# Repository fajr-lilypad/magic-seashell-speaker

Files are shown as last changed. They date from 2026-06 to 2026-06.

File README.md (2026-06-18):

# Seashell Speaker!

A bluetooth speaker that automatically plays when tilted, encased in a seashell case!

  

I came up with this idea when I was thinking about how to expand my audio projects. This was created for hackclub's fallout program, and after first creating an mp3 player, I though the next step would be to make something that could use bluetooth, and then I took it to the next level by making it tilt activated! By coincidence, this is my second ocean-related project, lol. The design was inspired by the story we all know about hearing the ocean come from a shell, and partly inspired by the purple magic conch shell from spongebob, lol.



# Cad Screenshots

<table>
   <tr>
      <td>
   
</td>
      <td>
   
      </td>
   </tr>
</table>

<table>
  <tr>
    <td>
    
    </td>
    <td>
    
    </td>
    <td>
      
    </td>
  </tr>
</table>

Cad Notes:
- Okay, so CAD took a WHILE. Creating such an organic shape was difficult, so ended up relying on the revolve, sweep, and coil tools. Since there arent any tutorials online for creating this type of shell in Fusion either, I had to experiment with blender along with borrowing pieces of 3d models online. Once I had a shape i was happy with, I turned it into a case by splitting it in half, adding holes for magnets, and enclosure for the speaker standoffs for the pcb, and holes for the speaker wires.
- The case itself is pretty easy to use, and I'm happy with how it turned out. If I could go back and change anything, I'd definetly check before hand that my case and pcb were compatible. Orginally, I had planned to tuck my pcb away in the lip/opening of the shell. However, that would be pretty mush impossible without making a HUGE shell case, so I had to basically do a whole redesign of the pcb and case.

# PCB Screenshots

<table>
  <tr>
    <td>
    
    </td>
    <td>
    
    </td>
    <td>
      
    </td>
  </tr>
</table>

  PCB Notes:
   - For the PCB, I did have to go thorugh a few versions. I mostly focused on creating super compact board without hindering the esp32's antenna, which wasn't too bad. However, my first designs were too big too fit in the case, so I had to go back to the drawing board, where I decided to make a round pcb that would sit between the top and bottom halves of the shell.
   - This pcb includes a tilt sensor, charging module, switch, esp32, speaker output headers, and more (see bom)

# Schematic Screenshot
 
 

 # Zine !!



 # BOM

 | Item                 | Purpose                       | #        | Cost   | Supplier           | Link                                                                                                                                                                                                                                                                                                                                                                                                                                                                                                                                                                                                                                                                                                                                                                                                                                                                                                                                       |
|----------------------|-------------------------------|----------|--------|--------------------|--------------------------------------------------------------------------------------------------------------------------------------------------------------------------------------------------------------------------------------------------------------------------------------------------------------------------------------------------------------------------------------------------------------------------------------------------------------------------------------------------------------------------------------------------------------------------------------------------------------------------------------------------------------------------------------------------------------------------------------------------------------------------------------------------------------------------------------------------------------------------------------------------------------------------------------------|
| SW-520D              | Sensor                        | 1        | $1.13  | Aliexpress         | https://www.aliexpress.us/item/3256805875302445.html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                                                                                                                                                                |
| ESP32                | Microcontroller               | 1        | $3.13  | Aliexpress         | https://www.aliexpress.us/item/3256807714347051.html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           |
| MAX98357A            | Amplifier                     | 1        | $1.78  | Aliexpress         | https://www.aliexpress.us/item/3256805196806369.html?gatewayAdapt=glo2usa4itemAdapt                                                                                                                                                                                                                                                                                                                                                                                                                                                                                                                                                                                                                                                                                                                                                                                                                                                        |
| Small Round Magnets  | Enclosure snaps               | 1        | $0.99  | Aliexpress         | https://www.aliexpress.us/item/3256810289404806.html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                                                                                                                                                   |
| 15mm speaker         | Speaker                       | 1        | $2.17  | Aliexpress         | https://www.aliexpress.us/item/3256809180147331.html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 |
| 3.7V Lithium Battery | Battery                       | 1        | $6.67  | Aliexpress         | https://www.aliexpress.us/item/3256803431098963.html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                                                                                                                                                                                                                                                                             |
| TP4056 Module        | Charging Module               | 1        | $0.82  | Aliexpress         | https://www.aliexpress.us/item/3256808777213556.html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                                                                                                                                                                                         |
| AP2112K              | Voltage Regulator             | 1        | $0.26  | Mouser             | https://www.mouser.com/ProductDetail/Diodes-Incorporated/AP2112K-33TRG1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                                                                                                                                                                                                                                                                                                                                                                                                                                                                                                                                                                                                                                                                                                                                                        |
| 3Pin Slide Switch    | Off/On                        | 1        | $0.90  | Aliexpress         | https://www.aliexpress.us/item/2255801021214741.html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                                                                                                                                                   |
| CH340C               | Serial Chip                   | 1        | $0.94  | Aliexpress         | https://www.aliexpress.us/item/3256809981619787.html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                                                                                                                                                   |
| JST 2 Pin Connector  | battery input, speaker output | 2        | $1.97  | Aliexpress         | https://www.aliexpress.us/item/3256808498055527.html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                                                                                                                                                    |
| USB C Receptacle     | Data Input                    | 1        | $2.02  | Aliexpress         | https://www.aliexpress.us/item/3256809263109556.html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                                                                                                                                                               |
| WS2812B              | LED                           | 2        | $0.20  | Ebee               | https://www.ebee.com/product-detail/worldsemi-ws2812b-v5-w_617514.html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                                                                                                                                                                                                                                                                                                                                                                                                                                                                                                                                                                                                                                                                                |
| 74ACHCT125           | Quad Level Shifter            | 1        | $1.50  | Adafruit           | https://www.adafruit.com/product/1787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                                                                                                                                                                                                                                                                                                                                                                                                                                                                                                                                                                                                                                                                                                                  |
| 10uF C               | Capacitor                     | 3        | $0.40  | Digikey            | https://www.digikey.com/en/products/detail/kyocera-avx/REA0511100M025K/20096372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                                                                                                                                                                                                                                                                                                                                                                                                                                                                                                                                                                                                                                                          |
| 0.1uF C              | Capacitor                     | 5        | $0.32  | Sparkfun           | https://www.sparkfun.com/capacitor-ceramic-0-1uf.html                                                                                                                                                                                                                                                                                                                                                                                                                                                                                                                                                                                                                                                                                                                                                                                                                                                                                      |
| 5.1K R               | Resistor                      | 2        | $0.08  | Electronix Express | https://www.elexp.com/products/130155-1kres-1-watt-5-5-1-k-ohm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                                                                                                                                                                                                                                                                                                                                                                                                                                                                                                                                                                                                                                                               |
| 330 R                | Resistor                      | 1        | $0.15  | Newark             | https://www.newark.com/multicomp-pro/mccfr01sj0331a10/carbon-film-resistor-330-ohm-1w/dp/59K8549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|pcrid||plid||kword||match|e|slid||product|59K8549|pgrid|1231453304461926|ptaid|pla-4580565455222458|&msclkid=0d6d44d2aa3b1af1a3812efec2f401f3                                                                                                                                                                                                                                                                                                                                                                                                                                                                                                                                                                                                                                                     |
| 10K R                | Resistor                      | 3        | $0.19  | Newark             | https://www.newark.com/multicomp-pro/mf12-10k/res-10k-125mw-axial-metal-film/dp/38K5401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                                                                                                                                                                                                                                                                                                                                                                                                                                                                                                                                                                                                                   |
| 100K R               | Resistor                      | 1        | $0.24  | Newark             | https://www.newark.com/ohmite/mox70031003bye/resistor-metal-film-100k-0-25w/dp/49AJ2825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|pcrid||plid||kword||match|e|slid||product|49AJ2825|pgrid|1231453304461926|ptaid|pla-4580565455222458|&msclkid=8346f4e1e0f2133c086d9ecd89969e59                                                                                                                                                                                                                                                                                                                                                                                                                                                                                                                                                                                                                                                             |
| S8050                | Transistor                    | 1        | $0.84  | Aliexpress         | https://www.aliexpress.us/item/3256808228534673.html?src=google&gatewayAdapt=glo2usa                                                                                                                                                                                                                                                                                                                                                                                                                                                                                                                                                                                                                                                                                                                                                                                                                                                       |
| BC847                | Transistor                    | 1        | $0.19  | Mouser             | https://www.mouser.com/ProductDetail/Nexperia/BC847235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                                                                                                                                                                                                                                                                                                                                                                                                                                                                                                                                                                        |
| PCB Order            | PCB                           | 1        | $2.10  | JLCPCB             |                                                                                                                                                                                                                                                                                                                                                                                                                                                                                                                                                                                                                                                                                                                                                                                                                                                                                                                                            |
|                      |                               | Subtotal | $28.99 |                    |                                                                                                                                                                                                                                                                                                                                                                                                                                                                                                                                                                                                                                                                                                                                                                                                                                                                                                                                            |

## Firmware

Unlike my previous audio projects, instead of using a micro sd card storing songs played by a df player, I used bluetooth connection via an esp32 and a BluetoothA2DPSink library I found from user pschatzmann. The code is fairly simple, and checks the tilt sensor in the background periodically, intercepting when a tilt is detected to pause/play audio.

## Build Guide
1. 3D print Case, ensure that standoffs and holes are secure and remove all supports.
2. Collect all electronic parts and perform breadboard testing before soldering onto custom pcb
3. Flash fimrware with new pcb, connect to bluetooth so you see "Bluetooth Speaker Audio Ready to Pair!" message printed.
4. Test out tilt puasing/playing audio
5. Mount fully charged pcb onto built in standoffs in top of case.
6. Place speaker in enclosure, thread wires through holes and plug into headers in pcb.
7. Place magnets in small holes in shell case, snap case shut.

## Notes and Acknowledgements
- Thank you to *hackclub* and the *fallout* team for this oppurtunity and for making this project possible!

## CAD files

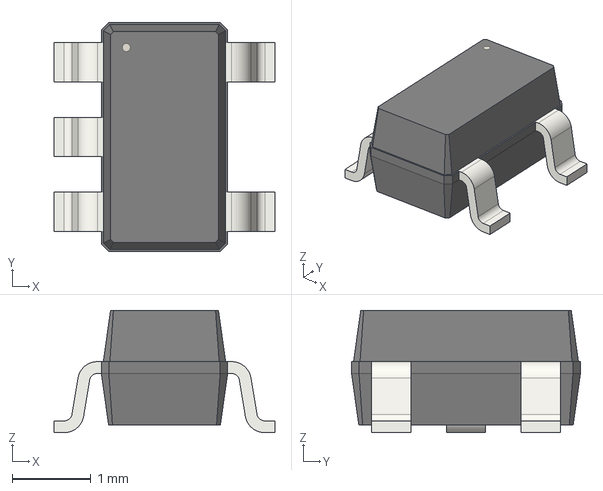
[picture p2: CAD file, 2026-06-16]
CAD/PCB Files/Electronics/SOT-23-5.step
2.80 x 2.90 x 1.55 mm

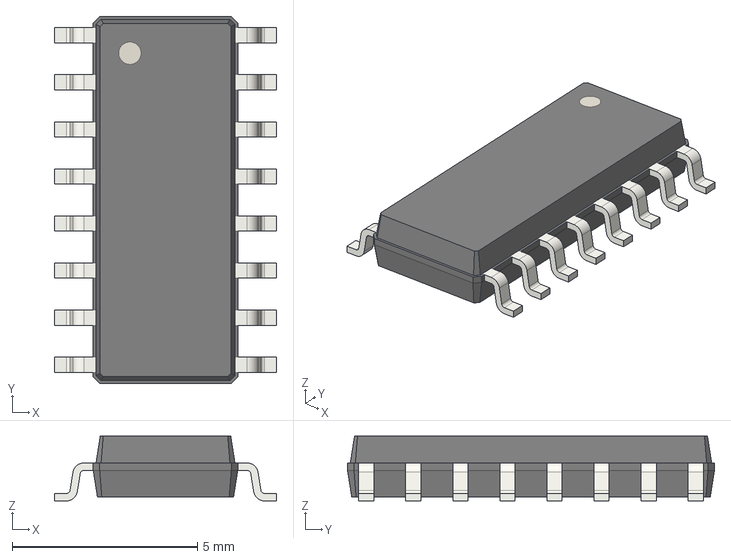
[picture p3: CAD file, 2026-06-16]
CAD/PCB Files/Electronics/SOIC-16_3.9x9.9mm_P1.27mm.step
6.00 x 9.90 x 1.75 mm

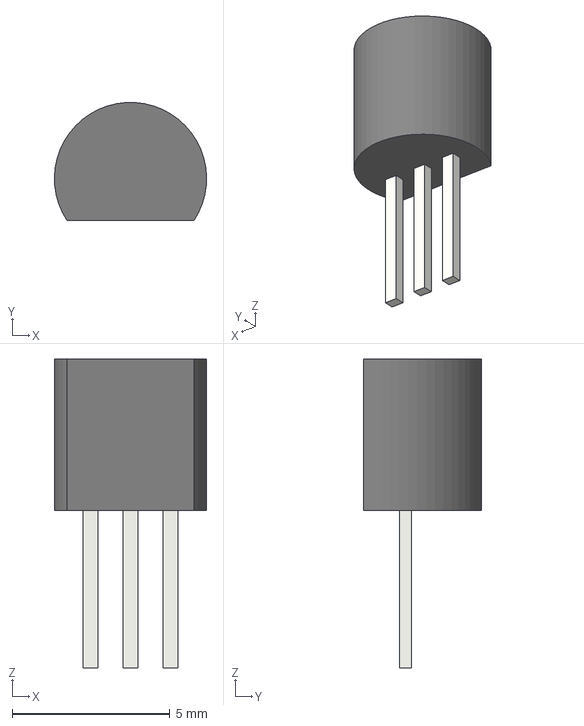
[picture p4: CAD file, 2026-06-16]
CAD/PCB Files/Electronics/TO-92_Inline Transistor.step
4.83 x 3.74 x 9.80 mm

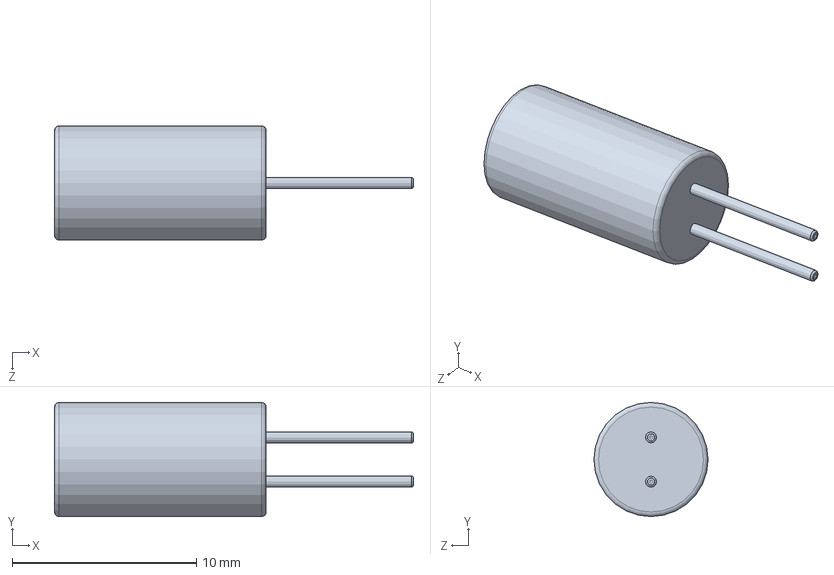
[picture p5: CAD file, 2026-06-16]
CAD/PCB Files/Electronics/SW-520D.SLDPRT
19.5 x 6.20 x 6.20 mm

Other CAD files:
pcb (no components).step

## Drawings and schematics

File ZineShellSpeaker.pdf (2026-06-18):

# magic shell bluetooth

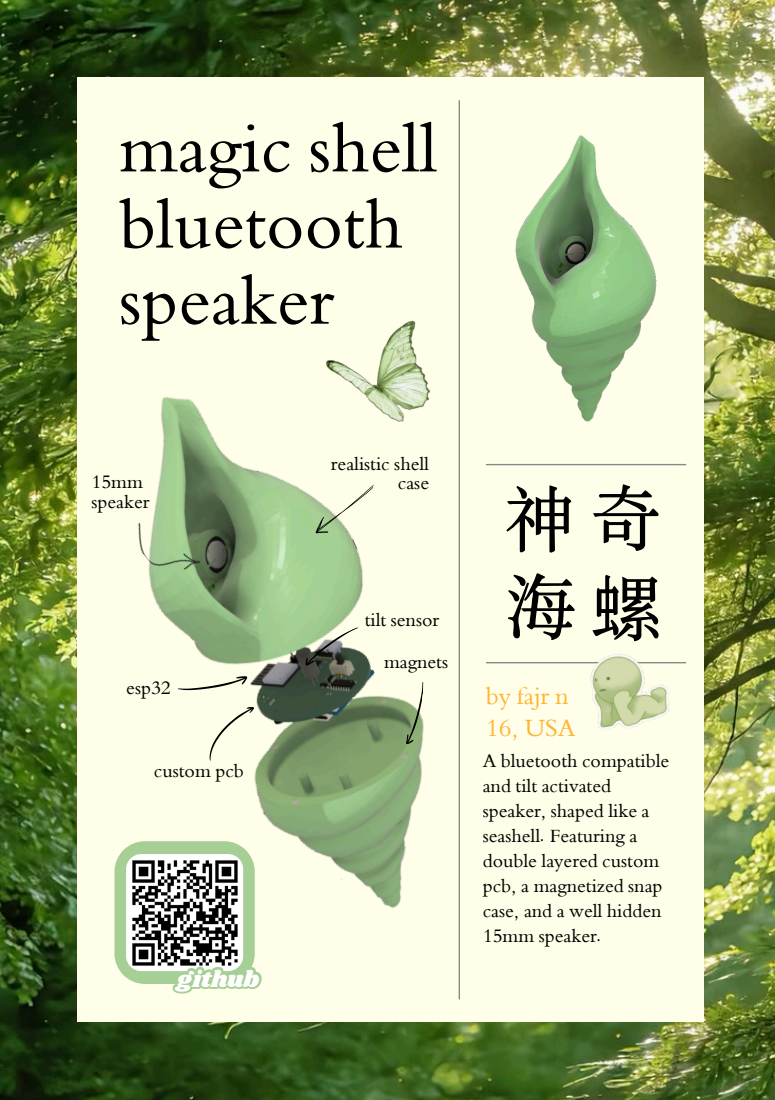
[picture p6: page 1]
speaker; custom pcb; realistic shell; case; esp32; ggiitthhuubb

tilt sensor
magnets
by fajr n
16, USA
A bluetooth compatible
and tilt activated
speaker, shaped like a
seashell. Featuring a
double layered custom
pcb, a magnetized snap
case, and a well hidden
15mm speaker.

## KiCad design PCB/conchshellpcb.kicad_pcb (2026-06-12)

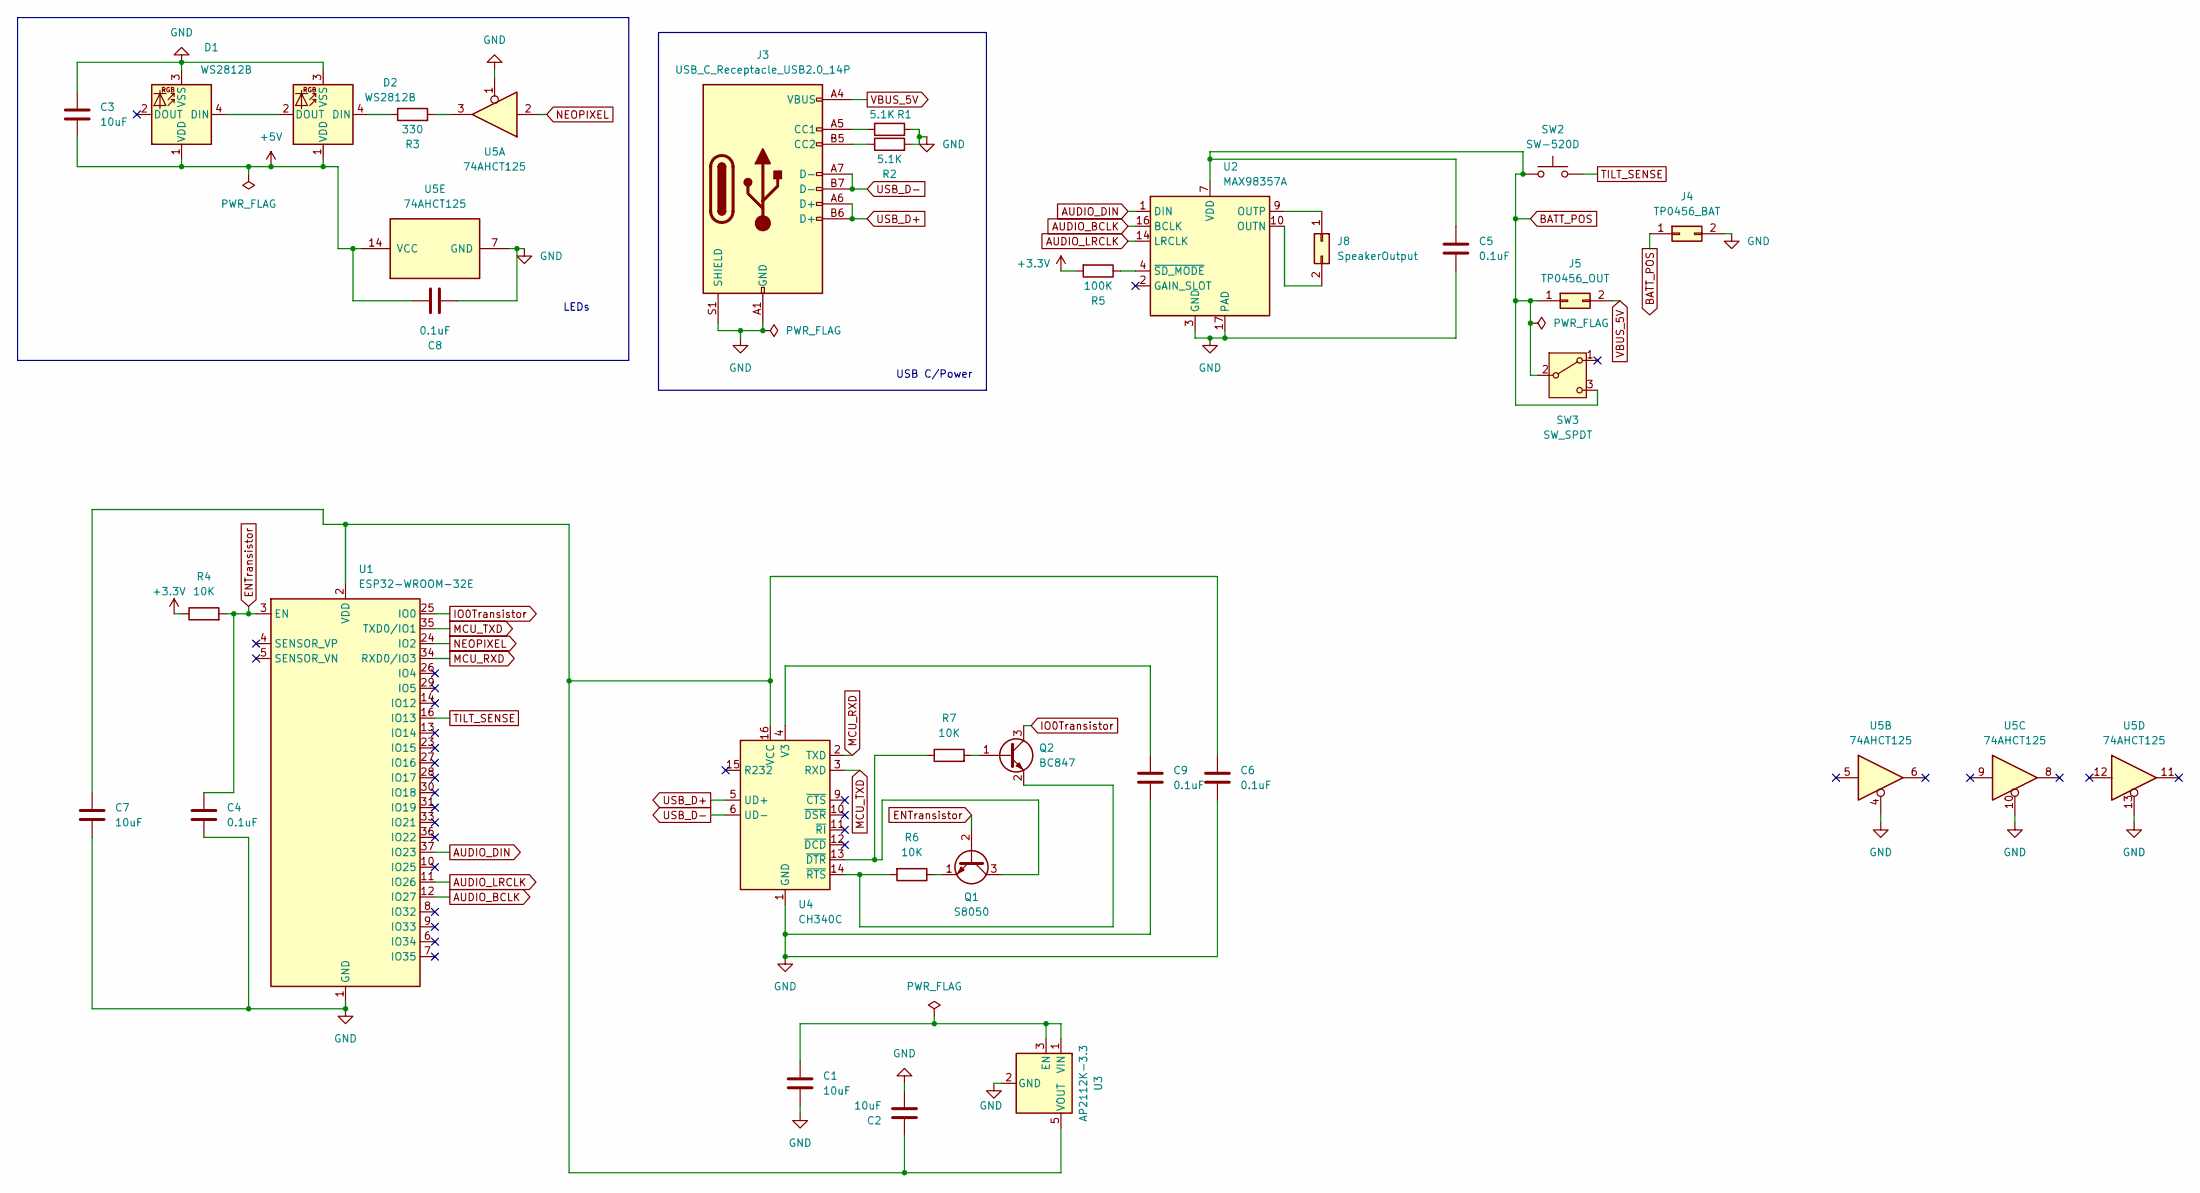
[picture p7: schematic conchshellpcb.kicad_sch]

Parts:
C1, C2, C3, C7: 10uF; C_0603_1608Metric
C4, C5, C6, C8, C9: 0.1uF; C_0402_1005Metric
D1, D2: WS2812B; LED_WS2812B_PLCC4_5.0x5.0mm_P3.2mm
J3: USB_C_Receptacle_USB2.0_14P; USB_C_Receptacle_HRO_TYPE-C-31-M-12
J4: TP0456_BAT; Batside
J5: TP0456_OUT; Outside
J8: SpeakerOutput; PinHeader_1x03_P2.54mm_Vertical
Q1: S8050; TO-92_Inline
Q2: BC847; SOT-23
R1, R2: 5.1K; R_0402_1005Metric
R3: 330; R_0402_1005Metric
R4, R6, R7: 10K; R_0402_1005Metric
R5: 100K; R_0402_1005Metric
SW2: SW-520D; PinHeader_1x02_P2.54mm_Vertical
SW3: SW_SPDT; SW_Slide_SPDT_Straight_CK_OS102011MS2Q
U1: ESP32-WROOM-32E; ESP32-WROOM-32D
U2: MAX98357A; TQFN-16-1EP_3x3mm_P0.5mm_EP1.6x1.6mm
U3: AP2112K-3.3; SOT-23-5
U4: CH340C; SOIC-16_3.9x9.9mm_P1.27mm
U5: 74AHCT125; DIP794W45P254L1930H508Q14

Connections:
+3.3V: R4.1, R5.2
+5V: C3.2, C8.1, D1.1 (VDD), D2.1 (VDD), U5.14 (VCC)
AUDIO_BCLK: U1.12 (IO27), U2.16 (BCLK)
AUDIO_DIN: U1.37 (IO23), U2.1 (DIN)
AUDIO_LRCLK: U1.11 (IO26), U2.14 (LRCLK)
BATT_POS: C5.1, J4.1, J5.1, SW2.1, SW3.2 (B), SW3.3 (C), U2.7 (VDD), U2.8 (VDD)
ENTransistor: C4.1, Q1.2 (B), R4.2, U1.3 (EN)
GND: C1.2, C2.1, C3.1, C4.2, C5.2, C6.2, C7.2, C8.2, C9.2, D1.3 (VSS), D2.3 (VSS), J3.A1 (GND), J3.A12 (GND), J3.B1 (GND), J3.B12 (GND), J3.S1 (SHIELD), J4.2, R1.2, R2.2, U1.1 (GND), U1.15 (GND), U1.38 (GND), U1.39 (GND), U2.3 (GND), U2.11 (GND), U2.15 (GND), U2.17 (PAD), U3.2 (GND), U4.1 (GND), U5.1, U5.4, U5.7 (GND), U5.10, U5.13
IO0Transistor: Q2.3 (C), U1.25 (IO0)
MCU_RXD: U1.34 (RXD0/IO3), U4.2 (TXD)
MCU_TXD: U1.35 (TXD0/IO1), U4.3 (RXD)
NEOPIXEL: U1.24 (IO2), U5.2
unnamed: D1.4 (DIN), D2.2 (DOUT)
unnamed: D2.4 (DIN), R3.1
unnamed: J3.A5 (CC1), R1.1
unnamed: J3.B5 (CC2), R2.1
unnamed: J8.1, U2.9 (OUTP)
unnamed: J8.2, U2.10 (OUTN)
unnamed: Q1.3 (C), R7.1, U4.13 (~DTR)
unnamed: Q1.1 (E), R6.1
unnamed: Q2.1 (B), R7.2
unnamed: Q2.2 (E), R6.2, U4.14 (~RTS)
unnamed: R3.2, U5.3
unnamed: C2.2, C6.1, C7.1, U1.2 (VDD), U3.5 (VOUT), U4.16 (VCC)
unnamed: R5.1, U2.4 (~SD_MODE)
unnamed: C1.1, U3.1 (VIN), U3.3 (EN)
unnamed: C9.1, U4.4 (V3)
TILT_SENSE: SW2.2, U1.16 (IO13)
USB_D+: J3.A6 (D+), J3.B6 (D+), U4.5 (UD+)
USB_D-: J3.A7 (D-), J3.B7 (D-), U4.6 (UD-)
VBUS_5V: J3.A4 (VBUS), J3.A9 (VBUS), J3.B4 (VBUS), J3.B9 (VBUS), J5.2

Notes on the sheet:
USB C/Power
LEDs

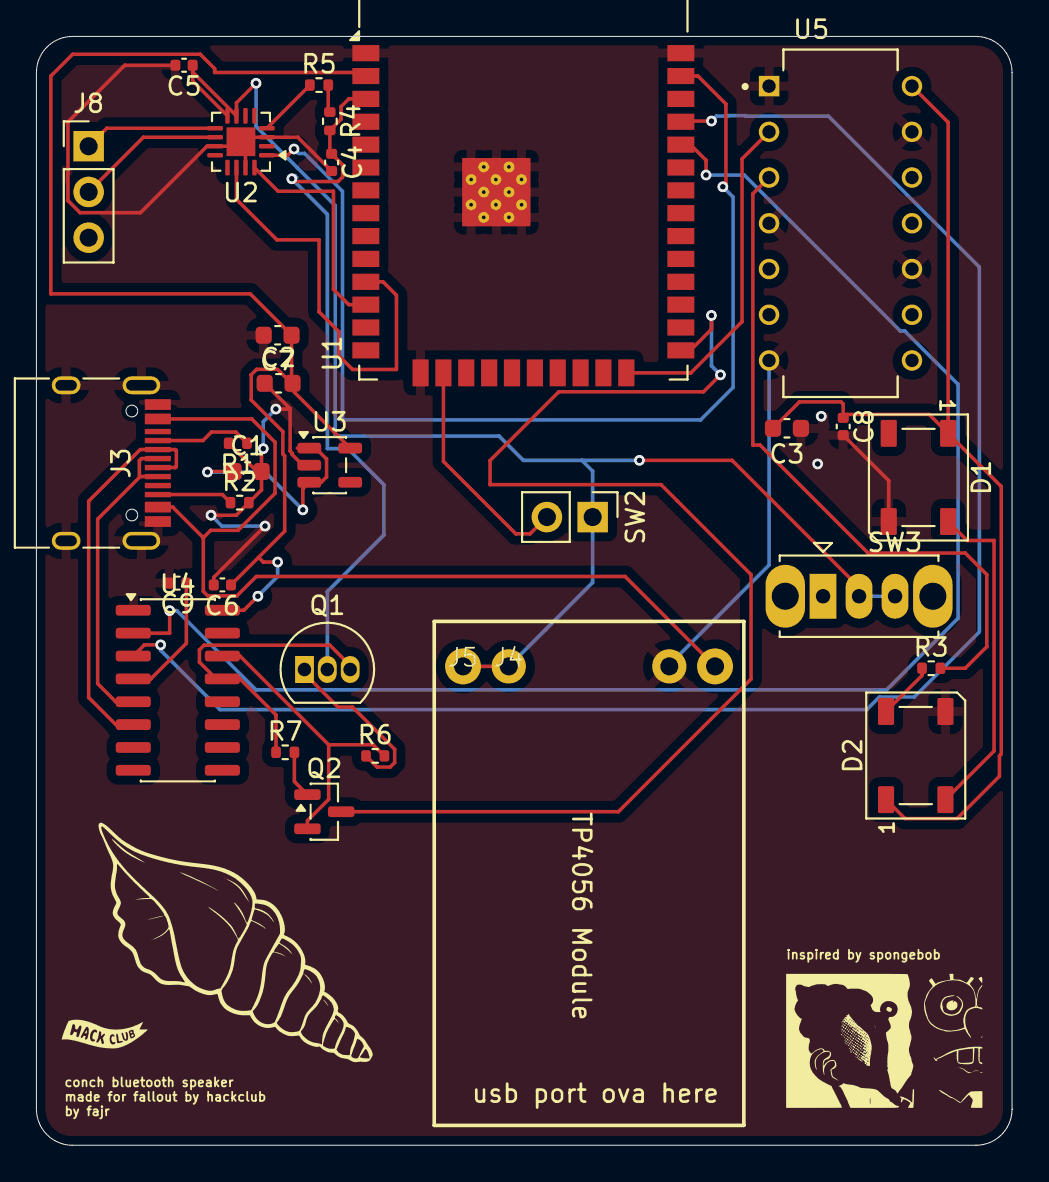
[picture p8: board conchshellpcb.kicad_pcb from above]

Board: 2 copper layers, 54.2 x 61.6 mm, 31 parts (0 on the bottom side), 31 nets.

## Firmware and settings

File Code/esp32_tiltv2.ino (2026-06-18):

#include "ESP_I2S.h"         
#include "BluetoothA2DPSink.h" 

// Defining pins
#define I2S_BCLK          26  // AUDIO_BCLK on IO26
#define I2S_LRCK          27  // AUDIO_LRCLK on IO27
#define I2S_DOUT          25  // AUDIO_DIN on IO25

#define TILT_SWITCH_PIN   12  // SW2 connected to IO12

// Initialize I2S
I2SClass i2s;

// Pass the I2S driver instance into the Bluetooth sink constructor
BluetoothA2DPSink a2dp_sink(i2s);

void setup() {
  Serial.begin(115200);

  //Configure the Tilt Switch
  pinMode(TILT_SWITCH_PIN, INPUT_PULLUP);

  //Configure the I2S hardware pin connections
  i2s.setPins(I2S_BCLK, I2S_LRCK, I2S_DOUT, -1, -1); // (BCLK, WS/LRCK, DOUT, DIN, MCLK)

  // 3. Start the Bluetooth Speaker
  a2dp_sink.start("My Magic Shell");
  
  Serial.println("Bluetooth Speaker Audio Ready to Pair!");
}

void loop() {
  int switchState = digitalRead(TILT_SWITCH_PIN);

  if (switchState == LOW) {
    //shell is level, do nothing and let the music play normally
  } else {
    Serial.println("Shell Tilted! Pausing Spotify...");
    //shell is tilted, force phone to PAUSE!
    if (a2dp_sink.is_connected()) {
        a2dp_sink.pause(); 
    }
  }

  delay(300); // Check the tilt switch a few times a second
}

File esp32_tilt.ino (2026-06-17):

_#include "ESP_I2S.h" // Modern ESP32 Core v3+ Audio Driver

// Define your exact schematic pins
#define TILT_SWITCH_PIN   12  // SW2 connected to IO12
#define I2S_BCLK          26  // AUDIO_BCLK on IO26
#define I2S_LRCK          27  // AUDIO_LRCLK on IO27
#define I2S_DOUT          25  // AUDIO_DIN on IO25

// Create the modern audio output object
I2SClass i2s;

void setup() {
  Serial.begin(115200);
  
  //Configure the Tilt Switch pin with internal pull-up resistor
  pinMode(TILT_SWITCH_PIN, INPUT_PULLUP);

  // Initialize Modern I2S Driver pins
  i2s.setPins(I2S_BCLK, I2S_LRCK, I2S_DOUT, -1, -1); // (BCLK, WS/LRCK, DOUT, DIN, MCLK)
  
  // Start I2S
  // Mode, Sample Rate, Bits per Sample, and Channel Slot Mode
  if (!i2s.begin(I2S_MODE_STD, 44100, I2S_DATA_BIT_WIDTH_16BIT, I2S_SLOT_MODE_STEREO)) {
    Serial.println("Failed to initialize I2S audio module!");
    while (1); // Halt if audio fails
  }

  Serial.println("Sound-Only Hardware Initialized Successfully!");
}

void loop() {
  // Reading status of tilt sensor
  int switchState = digitalRead(TILT_SWITCH_PIN);

  if (switchState == LOW) {
    Serial.println("Shell Status: Level / Upright");
  } else {
    Serial.println("Shell Status: Tilted / Moved!");
  }

  delay(200); //delay
}
